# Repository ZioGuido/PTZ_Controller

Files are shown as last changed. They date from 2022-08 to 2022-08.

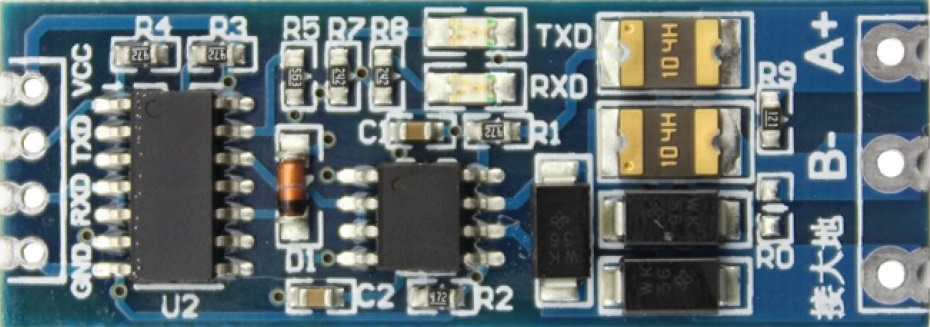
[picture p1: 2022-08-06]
PCB/UART TTL to RS485 Converter_1-1000x750.jpg

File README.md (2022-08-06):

# PTZ_Controller
Project for controlling PTZ camera via Arduino 

This project uses a Raspberry Pi Pico, an UART TTL to RS485 transceiver and a bunch of buttons to control PTZ cameras using the Pelco-D protocol.
I started this project because I was unhappy with the original controller we bought for controlling PTZ cameras in our TV studio. 
Those joystick controllers are made for the CCTV suirvellance cameras, they're not practical for the TV studio when recording or streaming live.

There were a series of issues:
- Too many button pushes to select a camera address (ESC, ADDR, number, ENTER)
- Too many button pushes to recall a preset (ESC, PRESET, number, ENTER)
- Joystick isn't precise
- Pan and Tilt speeds ramp up too rapidly using the joystick
- Buttons are too noisy
- LCD backlight goes off after a short while and you don't know which camera address it's on until you push a boutton

For these reasons I decided to make my owh controller without using a joystick, only big buttons and a couple of potentiometers.
Unfortunately, the camera we're using don't recognize the Zoom speed parameter from Pelco-D protocol, I should try writing a similar code but with Visca.
But for the remaining points, this controller is way better: silent buttons, just one push to select a camera (up to 4 addresses), 
just one push to recall a preset (up to 6 per camera), and you can vary Pan & Tilt speed while panning or tilting in a very smooth way.

One more thing:
This project makes use of 74HC595 and 74HC165 shift registers for controlling LEDs and reading button inputs.
These are serialized and share one common clock line, with the advantage of managing a high number of buttons and LEDs using only 4 pins of the CPU board.

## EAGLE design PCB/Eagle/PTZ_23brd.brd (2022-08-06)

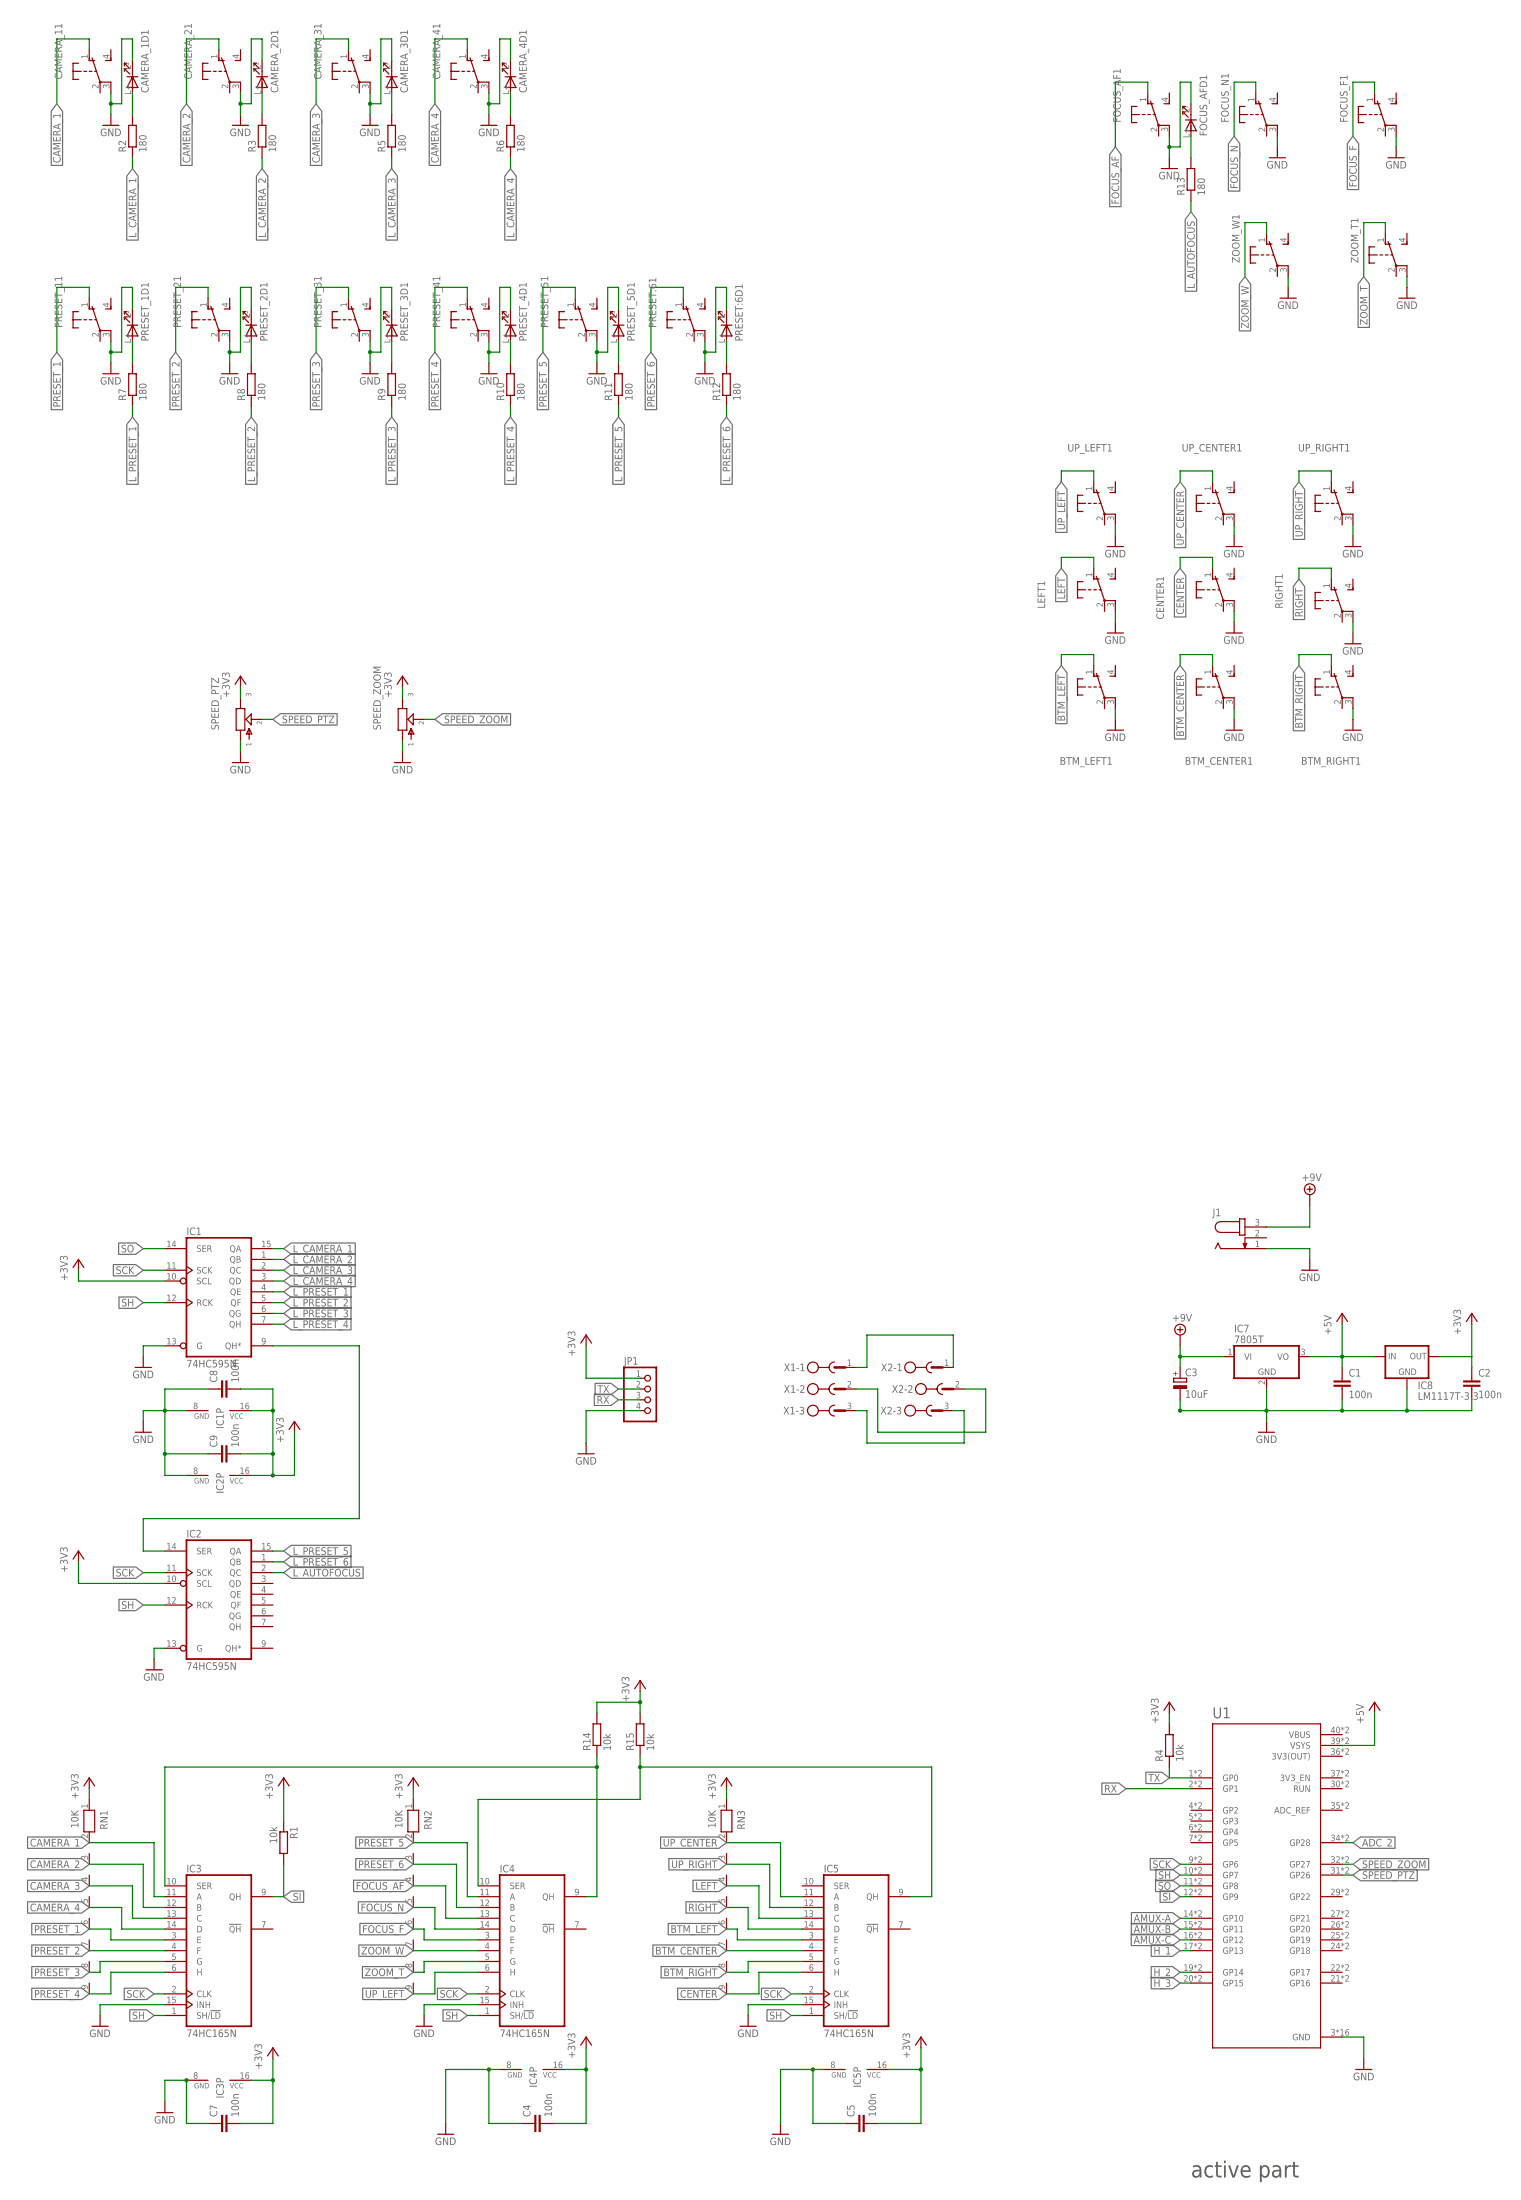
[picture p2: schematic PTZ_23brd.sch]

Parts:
BTM_CENTER: SWITCH-SHANPU_SRKLSHANPU_SPL; SWITCH-SHANPU_SPLG1YCS0014
BTM_LEFT: SWITCH-SHANPU_SRKLSHANPU_SPL; SWITCH-SHANPU_SPLG1YCS0014
BTM_RIGHT: SWITCH-SHANPU_SRKLSHANPU_SPL; SWITCH-SHANPU_SPLG1YCS0014
C1, C2, C4, C5, C7, C8, C9: 100n; C025-025X050
C3: 10uF; E2-5
CAMERA_1, CAMERA_2, CAMERA_3, CAMERA_4: SWITCH-SHANPU_SRKLSHANPU_SPL; SWITCH-SHANPU_SPLG1YCS0014
CENTER: SWITCH-SHANPU_SRKLSHANPU_SPL; SWITCH-SHANPU_SPLG1YCS0014
FOCUS_AF: SWITCH-SHANPU_SRKLSHANPU_SPL; SWITCH-SHANPU_SPLG1YCS0014
FOCUS_F: SWITCH-SHANPU_SRKLSHANPU_SPL; SWITCH-SHANPU_SPLG1YCS0014
FOCUS_N: SWITCH-SHANPU_SRKLSHANPU_SPL; SWITCH-SHANPU_SPLG1YCS0014
IC1, IC2: 74HC595N; DIL16
IC3, IC4, IC5: 74HC165N; DIL16
IC7: 7805T; TO220H
IC8: LM1117T-3.3; LM1117_TO220
J1: MOJO61_REAR42R_CON-JACK_JACK-PLUG; MOJO61_REAR42R_CON-JACK_2.1PCB
JP1: PINHD-1X4; 1X04
LEFT: SWITCH-SHANPU_SRKLSHANPU_SPL; SWITCH-SHANPU_SPLG1YCS0014
PRESET:6: SWITCH-SHANPU_SRKLSHANPU_SPL; SWITCH-SHANPU_SPLG1YCS0014
PRESET_1, PRESET_2, PRESET_3, PRESET_4, PRESET_5: SWITCH-SHANPU_SRKLSHANPU_SPL; SWITCH-SHANPU_SPLG1YCS0014
R1, R4, R14, R15: 10k; 0207/7
R2, R3, R5, R6, R7, R8, R9, R10, R11, R12, R13: 180; 0207/7
RIGHT: SWITCH-SHANPU_SRKLSHANPU_SPL; SWITCH-SHANPU_SPLG1YCS0014
RN1, RN2, RN3: 10K; RN-9
SPEED_PTZ: GM-POTS_POT-EU12MM; GM-POTS_RV120DF-40B1-(L)K
SPEED_ZOOM: GM-POTS_POT-EU12MM; GM-POTS_RV120DF-40B1-(L)K
U1: RPIPICO_RASPBERRY_PICO-NO_DEBUG; RPIPICO_PICO-PKG-NO_DEBUG
UP_CENTER: SWITCH-SHANPU_SRKLSHANPU_SPL; SWITCH-SHANPU_SPLG1YCS0014
UP_LEFT: SWITCH-SHANPU_SRKLSHANPU_SPL; SWITCH-SHANPU_SPLG1YCS0014
UP_RIGHT: SWITCH-SHANPU_SRKLSHANPU_SPL; SWITCH-SHANPU_SPLG1YCS0014
X1, X2: W232-3
ZOOM_T: SWITCH-SHANPU_SRKLSHANPU_SPL; SWITCH-SHANPU_SPLG1YCS0014
ZOOM_W: SWITCH-SHANPU_SRKLSHANPU_SPL; SWITCH-SHANPU_SPLG1YCS0014

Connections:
3V3(OUT): U1.36 (3V3(OUT)), U1.P$36 (3V3(OUT))
+3V3: C2.1, C4.2, C5.2, C7.2, C8.2, C9.2, IC1.10 (SCL), IC1.16 (VCC), IC2.10 (SCL), IC2.16 (VCC), IC3.16 (VCC), IC4.16 (VCC), IC5.16 (VCC), IC8.2 (OUT), JP1.1, R1.1, R4.2, R14.2, R15.2, RN1.1, RN2.1, RN3.1, SPEED_PTZ.3, SPEED_ZOOM.3
+5V: C1.1, IC7.3 (VO), IC8.3 (IN), U1.39 (VSYS), U1.P$39 (VSYS)
+9V: C3.+, IC7.1 (VI), J1.3
ADC_2: U1.34 (GP28), U1.P$34 (GP28)
AMUX-A: U1.14 (GP10), U1.P$14 (GP10)
AMUX-B: U1.15 (GP11), U1.P$15 (GP11)
AMUX-C: U1.16 (GP12), U1.P$16 (GP12)
BTM_CENTER: BTM_CENTER.1 (O), IC5.4 (F), RN3.7
BTM_LEFT: BTM_LEFT.1 (O), IC5.3 (E), RN3.6
BTM_RIGHT: BTM_RIGHT.1 (O), IC5.5 (G), RN3.8
CAMERA_1: CAMERA_1.1 (O), IC3.11 (A), RN1.2
CAMERA_2: CAMERA_2.1 (O), IC3.12 (B), RN1.3
CAMERA_3: CAMERA_3.1 (O), IC3.13 (C), RN1.4
CAMERA_4: CAMERA_4.1 (O), IC3.14 (D), RN1.5
CENTER: CENTER.1 (O), IC5.6 (H), RN3.9
FOCUS_AF: FOCUS_AF.1 (O), IC4.13 (C), RN2.4
FOCUS_F: FOCUS_F.1 (O), IC4.3 (E), RN2.6
FOCUS_N: FOCUS_N.1 (O), IC4.14 (D), RN2.5
GND: BTM_CENTER.3, BTM_LEFT.3, BTM_RIGHT.3, C1.2, C2.2, C3.-, C4.1, C5.1, C7.1, C8.1, C9.1, CAMERA_1.3, CAMERA_1.L- (C), CAMERA_2.3, CAMERA_2.L- (C), CAMERA_3.3, CAMERA_3.L- (C), CAMERA_4.3, CAMERA_4.L- (C), CENTER.3, FOCUS_AF.3, FOCUS_AF.L- (C), FOCUS_F.3, FOCUS_N.3, IC1.8 (GND), IC1.13 (G), IC2.8 (GND), IC2.13 (G), IC3.8 (GND), IC3.15 (INH), IC4.8 (GND), IC4.15 (INH), IC5.8 (GND), IC5.15 (INH), IC7.2 (GND), IC8.1 (GND), J1.1, JP1.4, LEFT.3, PRESET:6.3, PRESET:6.L- (C), PRESET_1.3, PRESET_1.L- (C), PRESET_2.3, PRESET_2.L- (C), PRESET_3.3, PRESET_3.L- (C), PRESET_4.3, PRESET_4.L- (C), PRESET_5.3, PRESET_5.L- (C), RIGHT.3, SPEED_PTZ.1, SPEED_ZOOM.1, U1.3 (GND), U1.8 (GND), U1.13 (GND), U1.18 (GND), U1.23 (GND), U1.28 (GND), U1.33 (GND), U1.38 (GND), U1.P$3 (GND), U1.P$8 (GND), U1.P$13 (GND), U1.P$18 (GND), U1.P$23 (GND), U1.P$28 (GND), U1.P$33 (GND), U1.P$38 (GND), UP_CENTER.3, UP_LEFT.3, UP_RIGHT.3, ZOOM_T.3, ZOOM_W.3
H_1: U1.17 (GP13), U1.P$17 (GP13)
H_2: U1.19 (GP14), U1.P$19 (GP14)
H_3: U1.20 (GP15), U1.P$20 (GP15)
LEFT: IC5.13 (C), LEFT.1 (O), RN3.4
L_AUTOFOCUS: IC2.2 (QC), R13.1
L_CAMERA_1: IC1.15 (QA), R2.1
L_CAMERA_2: IC1.1 (QB), R3.1
L_CAMERA_3: IC1.2 (QC), R5.1
L_CAMERA_4: IC1.3 (QD), R6.1
L_PRESET_1: IC1.4 (QE), R7.1
L_PRESET_2: IC1.5 (QF), R8.1
L_PRESET_3: IC1.6 (QG), R9.1
L_PRESET_4: IC1.7 (QH), R10.1
L_PRESET_5: IC2.15 (QA), R11.1
L_PRESET_6: IC2.1 (QB), R12.1
unnamed: IC1.9 (QH*), IC2.14 (SER)
unnamed: IC3.10 (SER), IC4.9 (QH), R14.1
unnamed: CAMERA_1.L+ (A), R2.2
unnamed: IC4.10 (SER), IC5.9 (QH), R15.1
unnamed: PRESET_2.L+ (A), R8.2
unnamed: X1.1, X2.1
unnamed: X1.2, X2.2
unnamed: X1.3, X2.3
unnamed: CAMERA_2.L+ (A), R3.2
unnamed: CAMERA_3.L+ (A), R5.2
unnamed: PRESET_3.L+ (A), R9.2
unnamed: CAMERA_4.L+ (A), R6.2
unnamed: FOCUS_AF.L+ (A), R13.2
unnamed: PRESET_4.L+ (A), R10.2
unnamed: PRESET_1.L+ (A), R7.2
unnamed: PRESET_5.L+ (A), R11.2
unnamed: PRESET:6.L+ (A), R12.2
PRESET_1: IC3.3 (E), PRESET_1.1 (O), RN1.6
PRESET_2: IC3.4 (F), PRESET_2.1 (O), RN1.7
PRESET_3: IC3.5 (G), PRESET_3.1 (O), RN1.8
PRESET_4: IC3.6 (H), PRESET_4.1 (O), RN1.9
PRESET_5: IC4.11 (A), PRESET_5.1 (O), RN2.2
PRESET_6: IC4.12 (B), PRESET:6.1 (O), RN2.3
RIGHT: IC5.14 (D), RIGHT.1 (O), RN3.5
RX: JP1.3, U1.2 (GP1), U1.P$2 (GP1)
SCK: IC1.11 (SCK), IC2.11 (SCK), IC3.2 (CLK), IC4.2 (CLK), IC5.2 (CLK), U1.9 (GP6), U1.P$9 (GP6)
SH: IC1.12 (RCK), IC2.12 (RCK), IC3.1 (SH/!LD), IC4.1 (SH/!LD), IC5.1 (SH/!LD), U1.10 (GP7), U1.P$10 (GP7)
SI: IC3.9 (QH), R1.2, U1.12 (GP9), U1.P$12 (GP9)
SO: IC1.14 (SER), U1.11 (GP8), U1.P$11 (GP8)
SPEED_PTZ: SPEED_PTZ.2, U1.31 (GP26), U1.P$31 (GP26)
SPEED_ZOOM: SPEED_ZOOM.2, U1.32 (GP27), U1.P$32 (GP27)
TX: JP1.2, R4.1, U1.1 (GP0), U1.P$1 (GP0)
UP_CENTER: IC5.11 (A), RN3.2, UP_CENTER.1 (O)
UP_LEFT: IC4.6 (H), RN2.9, UP_LEFT.1 (O)
UP_RIGHT: IC5.12 (B), RN3.3, UP_RIGHT.1 (O)
VBUS: U1.40 (VBUS), U1.P$40 (VBUS)
ZOOM_T: IC4.5 (G), RN2.8, ZOOM_T.1 (O)
ZOOM_W: IC4.4 (F), RN2.7, ZOOM_W.1 (O)

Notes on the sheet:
active part

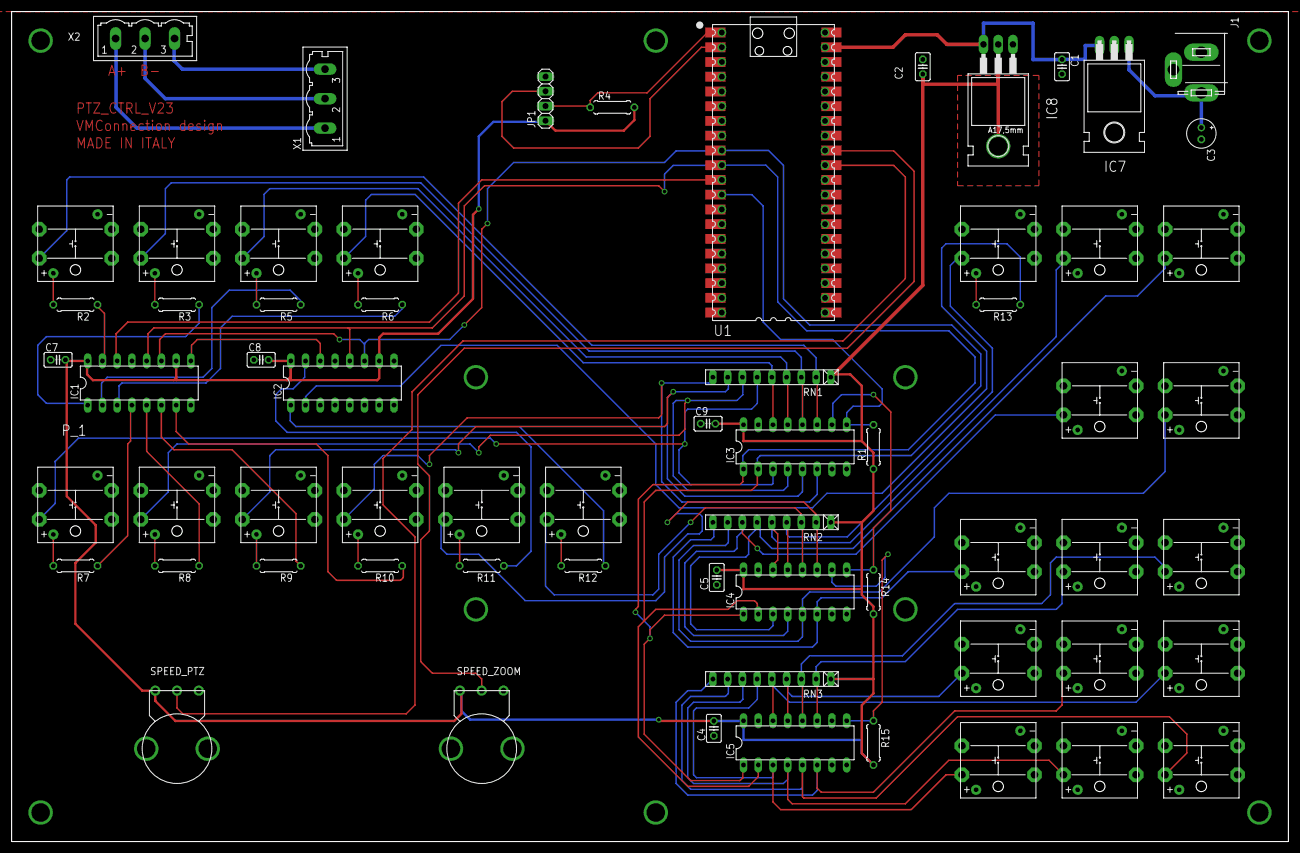
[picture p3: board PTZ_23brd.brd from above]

Board: 2 copper layers, 220.0 x 143.0 mm, 64 parts (0 on the bottom side), 73 nets.

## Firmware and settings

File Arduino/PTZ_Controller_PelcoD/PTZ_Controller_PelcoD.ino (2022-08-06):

/////////////////////////////////////////////////////////////////////////////////////
/////////////////////////////////////////////////////////////////////////////////////
// Controller for PTZ camera using PelcoD protocol
// Based on Raspberry Pi Pico + RS485 transceiver
// All buttons and LEDs are scanned/driven using 74HC165 & 74HC595 shift registers
//
// Code by Guido Scognamiglio - www.GenuineSoundware.com
// Last update: 21 July 2022
//


#include "../../GSiSRIO/SRIO.h"

GSiSRIO SRIO;
auto SRIOTimer = millis();
auto ButtonTimer = 0U;

byte PINS_CameraSelectBtn[] = { 0, 1, 2, 3 };
byte PINS_PresetBtn[] = { 4, 5, 6, 7, 8, 9 };
#define PIN_FOCUS_AUTO	10
#define PIN_FOCUS_F		11
#define PIN_FOCUS_N		12
#define PIN_ZOOM_W		13
#define PIN_ZOOM_T		14
#define PIN_UP_LEFT		15 
#define PIN_UP			16 
#define PIN_UP_RIGHT	17
#define PIN_LEFT		18
#define PIN_RIGHT		19 
#define PIN_DOWN_LEFT	20
#define PIN_DOWN		21
#define PIN_DOWN_RIGHT	22
byte PINS_PanTiltBtn[] = { 15, 16, 17, 18, 19, 20, 21, 22 };

// Remember: LED pins are reversed for each 595
byte LEDS_CameraSelect[] = { 7, 6, 5, 4 };
byte LEDS_Preset[] = { 3, 2, 1, 0, 15, 14 };
#define LED_FOCUS_AUTO	 13

byte Camera = 0;
byte Preset = 0;

byte CameraAddr = 1;
byte PT_Speed = 1;
byte ZOOM_Speed = 1;

byte PanningOrTilting = 0;

int ADC_Value[2] = { -1, -1 };
int ADC_Ports[2] = { A0, A1 };
int ADC_Select = 0;

int PresetPerCam[4] = { -1, -1, -1, -1 };

int BlinkLed = -1, BlinkT = 0, BlinkS = 0, BlinkC = 0;

void ReadADC(int port)
{
	// ADC Resolution is 12 bits
	auto value = 0; 
	for (int i = 0; i < 10; ++i) value += analogRead(ADC_Ports[port]);
	value /= 10;

	auto diff = abs(value - ADC_Value[port]);
	if (diff <= 8) return;
	ADC_Value[port] = value;

	//Serial.printf("ADC n. %d - Value = %d\n", port, value);
	
	// Pot 0 = Pan/Tilt speed
	if (port == 0)
	{
		int newSpeed = value >> 6; // Pan/Tilt speed is 6 bits 0x00 ~ 0x3F
		if (PT_Speed != newSpeed)
		{
			PT_Speed = newSpeed;

			if (PanningOrTilting > 0)
				SendPelcoD(CameraAddr, 0x00, PanningOrTilting, PT_Speed, PT_Speed);
		}
	}
	
	// Pot 1 = Zoom speed	
	if (port == 1)
	{
		 auto newSpeed = value >> 10; // only 2 bits!
		 if (ZOOM_Speed != newSpeed)
		 {
			 ZOOM_Speed = newSpeed;
			 SendPelcoD(CameraAddr, 0x00, 0x25, 0x00, ZOOM_Speed);
		 }
	}
	//Serial.printf("PT_Speed = %d - ZOOM_Speed = %d\n", PT_Speed, ZOOM_Speed);
}

void SendPelcoD(uint8_t addr, uint8_t cmd1, uint8_t cmd2, uint8_t data1, uint8_t data2)
{
	int sum = (addr + cmd1 + cmd2 + data1 + data2) % 0x100;
	uint8_t cmd[7] = { 0xFF, addr, cmd1, cmd2, data1, data2, sum };
	Serial1.write(cmd, 7);

	Serial.printf("Pelco-D: 0x%02X 0x%02X 0x%02X 0x%02X 0x%02X 0x%02X 0x%02X\n", cmd[0], cmd[1], cmd[2], cmd[3], cmd[4], cmd[5], cmd[6]);
}

void SelectCamera(byte cam)
{
	Serial.printf("Set Camera n. %d\n", cam + 1);

	Camera = cam;
	CameraAddr = Camera + 1;
	
	for (byte c = 0; c < 4; c++)
		SRIO.DOUT_PinSet(LEDS_CameraSelect[c], Camera == c);

	for (auto p = 0; p < 6; ++p)
		SRIO.DOUT_PinSet(LEDS_Preset[p], PresetPerCam[Camera] == p);
}

void NoPreset()
{
	PresetPerCam[Camera] = -1;

	for (auto p = 0; p < 6; ++p)
		SRIO.DOUT_PinSet(LEDS_Preset[p], 0);
}

void SavePreset(byte pNum)
{
	Serial.printf("Save Presetn n. %d\n", pNum + 1);
	
	SendPelcoD(CameraAddr, 0x00, 0x03, 0x00, pNum);
	PresetPerCam[Camera] = pNum;

	for (auto p = 0; p < 6; ++p)
		SRIO.DOUT_PinSet(LEDS_Preset[p], 0);

	BlinkLed = LEDS_Preset[pNum];
}

void RecallPreset(byte pNum)
{
	Serial.printf("Recall Presetn n. %d\n", pNum + 1);
	
	ButtonTimer = 0;
	PresetPerCam[Camera] = pNum;
	SendPelcoD(CameraAddr, 0x00, 0x07, 0x00, pNum);

	for (auto p = 0; p < 6; ++p)
		SRIO.DOUT_PinSet(LEDS_Preset[p], p == pNum);
}

void DIN_Notify(uint8_t pin, uint8_t value)
{
	// Button down
	if (value == 0)
	{
		switch (pin)
		{
		case PIN_UP_LEFT:		SendPelcoD(CameraAddr, 0x00, 0x0C, PT_Speed, PT_Speed); NoPreset(); PanningOrTilting = 0x0C; break;
		case PIN_UP:			SendPelcoD(CameraAddr, 0x00, 0x08, PT_Speed, PT_Speed); NoPreset(); PanningOrTilting = 0x08; break;
		case PIN_UP_RIGHT:		SendPelcoD(CameraAddr, 0x00, 0x0A, PT_Speed, PT_Speed); NoPreset(); PanningOrTilting = 0x0A; break;
		case PIN_LEFT:			SendPelcoD(CameraAddr, 0x00, 0x04, PT_Speed, PT_Speed); NoPreset(); PanningOrTilting = 0x04; break;
		case PIN_RIGHT:			SendPelcoD(CameraAddr, 0x00, 0x02, PT_Speed, PT_Speed); NoPreset(); PanningOrTilting = 0x02; break;
		case PIN_DOWN_LEFT:		SendPelcoD(CameraAddr, 0x00, 0x14, PT_Speed, PT_Speed); NoPreset(); PanningOrTilting = 0x14; break;
		case PIN_DOWN:			SendPelcoD(CameraAddr, 0x00, 0x10, PT_Speed, PT_Speed); NoPreset(); PanningOrTilting = 0x10; break;
		case PIN_DOWN_RIGHT:	SendPelcoD(CameraAddr, 0x00, 0x12, PT_Speed, PT_Speed); NoPreset(); PanningOrTilting = 0x12; break;

		case PIN_FOCUS_AUTO:	
			SendPelcoD(CameraAddr, 0x00, 0x2B, 0, 0);
			SRIO.DOUT_PinSet(LED_FOCUS_AUTO, 1);
			break;
		case PIN_FOCUS_N:		
			SRIO.DOUT_PinSet(LED_FOCUS_AUTO, 0);
			SendPelcoD(CameraAddr, 0x00, 0x2B, 0, 1);
			SendPelcoD(CameraAddr, 0x01, 0x00, 0, 0); 
			break;
		case PIN_FOCUS_F:		
			SRIO.DOUT_PinSet(LED_FOCUS_AUTO, 0);
			SendPelcoD(CameraAddr, 0x00, 0x2B, 0, 1);
			SendPelcoD(CameraAddr, 0x00, 0x80, 0, 0);
			break;

		case PIN_ZOOM_W:		
			SendPelcoD(CameraAddr, 0x00, 0x40, 0x00, 0x00);
			NoPreset();
			break;
		case PIN_ZOOM_T:		
			SendPelcoD(CameraAddr, 0x00, 0x20, 0x00, 0x00);
			NoPreset();
			break;

		default:
			for (auto c : PINS_CameraSelectBtn)
				if (pin == c)
					return SelectCamera(c);
			
			for (auto p : PINS_PresetBtn)
				if (pin == p)
				{
					ButtonTimer = 500; 
					return;
				}
		}
	}

	// Button up
	else
	{
		// Recall Preset
		for (auto p = 0; p < 6; ++p)
			if (pin == PINS_PresetBtn[p] && ButtonTimer > 1)
				return RecallPreset(p);

		// If one of the Pan/Tilt buttons is still depressed when another button has been released, take action
		for (auto p : PINS_PanTiltBtn)
			if (SRIO.DIN_PinGet(p) == 0)
				return DIN_Notify(p, 0);
		
		// Stop any movement when a button is released
		SendPelcoD(CameraAddr, 0, 0, 0, 0);
		PanningOrTilting = 0;
	}
}

void setup()
{
	Serial.begin(115200);
	Serial1.begin(9600);

	SRIO.Init(DIN_Notify);
	SRIO.SRIO_NumberSet(3);
	SRIO.DebounceSet(16);

	analogReadResolution(10); delay(100); analogReadResolution(12);

	SelectCamera(0);
	DIN_Notify(PIN_FOCUS_AUTO, 0);
}

void loop()
{
	// Run every millisecond
	if (millis() - SRIOTimer > 1)
	{
		SRIOTimer = millis();

		ReadADC(ADC_Select);
		ADC_Select = ADC_Select == 0 ? 1 : 0;

		SRIO.Run();

		// Button long press for saving presets?
		if (ButtonTimer > 0) ButtonTimer--;
		if (ButtonTimer == 1)
		{
			ButtonTimer = 0;
			for (auto p = 0; p < 6; ++p)
				if (SRIO.DIN_PinGet(PINS_PresetBtn[p]) == 0)
					return SavePreset(p);
		}

		if (BlinkLed >= 0)
		{
			if (++BlinkT >= 25)
			{
				BlinkT = 0;
				SRIO.DOUT_PinSet(BlinkLed, BlinkS);
				BlinkS = ~BlinkS;

				if (++BlinkC > 5)
				{
					BlinkC = 0;
					BlinkLed = -1;
					SRIO.DOUT_PinSet(BlinkLed, 1);
				}
			}
		}
	}
}

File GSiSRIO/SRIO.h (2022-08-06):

////////////////////////////////////////////////////////////////////////////////////////////////////////////////////
// GSiSRIO - by Guido Scognamiglio - www.GenuineSoundware.com
// 
// Functions for simultaneous use of 74HC565 (out) and 74HC165 (in) Shift Registers with shared clock lines.
// This method requires only 4 wires, and reads/writes to serialized SRs.
// Set pins according to the board you're using. This was originally made for the Raspberry Pi Pico.
// Change the definition of MAX_SRs	if you need to connect more than 4 SRs in series.
//
// Usage:
//  - Instantiate a GSiSRIO object and pass the desired pin numbers
//  - Call Init() in setup() and pass a callback function of type void(uint8_t pin, uint8_t value) that will be called
//    whenever an input pin changes its state.
//  - Call SRIO_NumberSet(number) to specify the number of SR in series in your circuit, from 1 to MAX_SRs.
//  - Call DebounceSet(number) to set the debounce delay in number of scan cycles.
//  - Call DOUT_PinSet(pin, value) to set an output pin high or low.
//  - Call DOUT_SRSet(uint8_t value) to set the an entire 595 at once.
//  - Call DIN_PinGet(pin) to get the state of an input pin at any time.
//  - Call DOUT_PinGet(pin) to get the state of an output pin at any time.
//  - Call Run() in your loop() at the desired speed. For LED and buttons 1KHz is more than enough.
//
// Last update: 15 June 2022
// (TO-DO: Could be optimized! Could use a data order option.)
//

#pragma once

#if 1
#define MAX_SRs	4

#define PIN_SCK 6   // To 595 SCK(11) / To 165 CLK(2)
#define PIN_SH  7   // To 595 RCK(12) / To 165 SH(1)
#define PIN_SO  8   // To 595 SER(14)
#define PIN_SI  9   // To 165 QH(9)

// Redefine these macros to use these routines on a platform other than Arduino, for instance wiringPi.
#define _SRIO_PINMODE(pin, mode) 			pinMode(pin, mode)
#define _SRIO_DIGITALWRITE(pin, status) 	digitalWrite(pin, status)
#define _SRIO_DIGITALREAD(pin) 				digitalRead(pin)

class GSiSRIO
{
public:
	using DIN_CallbackType = void(*)(uint8_t pin, uint8_t pin_value);
	DIN_CallbackType DIN_Callback = nullptr;

	// Specify PIN GPIO numbers or use the default assignments
	GSiSRIO(uint8_t _pin_sck = PIN_SCK, uint8_t _pin_sh = PIN_SH, uint8_t _pin_so = PIN_SO, uint8_t _pin_si = PIN_SI)
	{
		pin_sck = _pin_sck;
		pin_sh = _pin_sh;
		pin_so = _pin_so;
		pin_si = _pin_si;
	}

	//////////////////////////////////////////////////////////////////////////

	// Set the number of Shift Registers in series
	void SRIO_NumberSet(uint8_t num)
	{
		if (num > MAX_SRs) num = MAX_SRs;
		NumberOfShiftRegisters = num;
		SRNumberOfPins = num * 8;
	}

	// Set a 595 SR at once
	void DOUT_SRSet(uint8_t SR, uint8_t byteSet)
	{
		SR595ByteSet[SR] = byteSet;
	}

	// Set an output pin high or low
	void DOUT_PinSet(uint8_t pin, uint8_t pin_value)
	{
		uint8_t SR = pin >> 3; // / 8;
		uint8_t bit = pin & 7; // % 8;

		if (pin_value > 0)
			SR595ByteSet[SR] |= (1 << bit);
		else
			SR595ByteSet[SR] &= ~(1 << bit);
	}

	// Get the state of an input pin
	uint8_t DIN_PinGet(uint8_t pin)
	{
		uint8_t SR = pin >> 3; // / 8;
		uint8_t bit = pin & 7; // % 8;
		return (SR165ByteSet[SR] >> bit) & 1;
	}

	// Get the state of an output pin
	uint8_t DOUT_PinGet(uint8_t pin)
	{
		uint8_t SR = pin >> 3; // / 8;
		uint8_t bit = pin & 7; //  % 8;
		return (SR595ByteSet[SR] >> bit) & 1;
	}

	// Call once in setup() to set the debounce time in number of scan cycles
	void DebounceSet(uint8_t db)
	{
		//if (db < 2) db = 2;
		SRIODebounceAmount = db;
	}

	//////////////////////////////////////////////////////////////////////////

	// Call this in loop() at a regular interval
	void Run()
	{
		// Latch the 595 outputs and load the 165 inputs
		_SRIO_DIGITALWRITE(pin_sh, LOW);
		_SRIO_DIGITALWRITE(pin_sh, HIGH);
		_SRIO_DIGITALWRITE(pin_sck, LOW);

		for (uint8_t SR = 0; SR < NumberOfShiftRegisters; ++SR)
		{
			uint8_t datain = 0;

			for (uint8_t bit = 0; bit < 8; ++bit)
			{
				// Shift the outputs
				_SRIO_DIGITALWRITE(pin_so, (SR595ByteSet[NumberOfShiftRegisters - 1 - SR] >> bit) & 1);

				// Read the inputs
				datain <<= 1;
				if (_SRIO_DIGITALREAD(pin_si) == HIGH) datain = datain | 0x01;

				// Pulse clock
				_SRIO_DIGITALWRITE(pin_sck, HIGH);
				_SRIO_DIGITALWRITE(pin_sck, LOW);
			}

			SR165ByteSet[SR] = datain;
		}

		// Check DIN changes if a callback has been defined
		if (DIN_Callback != nullptr)
			CheckDINs();
	}

	// Call once in setup() to initialize the SRIO routinse
	// _callback = pass a callback of type void(uint8_t pin, uint8_t value) that will be called
	// whenever an input pin changes its state
	void Init(DIN_CallbackType _callback = nullptr)
	{
		DIN_Callback = _callback;

		_SRIO_PINMODE(pin_sck, OUTPUT);
		_SRIO_PINMODE(pin_sh, OUTPUT);
		_SRIO_PINMODE(pin_so, OUTPUT);
		_SRIO_PINMODE(pin_si, INPUT);

		_SRIO_DIGITALWRITE(pin_sh, HIGH);
		_SRIO_DIGITALWRITE(pin_sck, HIGH);
		_SRIO_DIGITALWRITE(pin_so, HIGH);
	}

private:
	uint8_t pin_sck, pin_sh, pin_so, pin_si;

	uint8_t SR595ByteSet[MAX_SRs] = { 0 };
	uint8_t SR165ByteSet[MAX_SRs] = { 0 };
	uint8_t NumberOfShiftRegisters = 1, SRNumberOfPins = 8;
	uint8_t SRDINStateOld[MAX_SRs * 8] = { 1 };
	uint8_t SRIODebounceCounter[MAX_SRs * 8] = { 0 }, SRIODebounceAmount = 32;

	// This is called in RunSRIO() if a callback has been set
	void CheckDINs()
	{
		for (auto pin = 0; pin < SRNumberOfPins; ++pin)
		{
			auto value = DIN_PinGet(pin);
			if (SRDINStateOld[pin] != value)
			{
				SRDINStateOld[pin] = value;

				if (SRIODebounceAmount < 2)
				{
					DIN_Callback(pin, value);
					continue;
				}

				SRIODebounceCounter[pin] = SRIODebounceAmount + 1;
			}

			if (SRIODebounceCounter[pin] > 0)
				SRIODebounceCounter[pin]--;

			if (SRIODebounceCounter[pin] == 1)
			{
				auto value = DIN_PinGet(pin);
				if (SRDINStateOld[pin] == value)
					DIN_Callback(pin, value);
			}
		}
	}
};

#endif
//
////////////////////////////////////////////////////////////////////////////////////////////////////////////////////
